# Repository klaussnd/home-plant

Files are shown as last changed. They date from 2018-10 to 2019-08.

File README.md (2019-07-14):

# An automatic watering system for home plants

An open source automatic plant watering system for pot plants in your home.
The system has been employed successfully in my home for several years.
It has a modular design and consists of a measurement module, an irrigation module, and a control module.
A full description as well as some theoretical background can be found [in this paper](http://kschn.users.sf.net/home-plant.pdf).

This repository will contain hardware, firmware, and software utilities.
I am currently in the process of extracting all relevant code from my private repositories.
For now, the repository already contains the hardware.
Code will follow soon.

All circuits and source code are licensed under the terms of the [GNU Affero General Public License](https://www.gnu.org/licenses/agpl-3.0.en.html).

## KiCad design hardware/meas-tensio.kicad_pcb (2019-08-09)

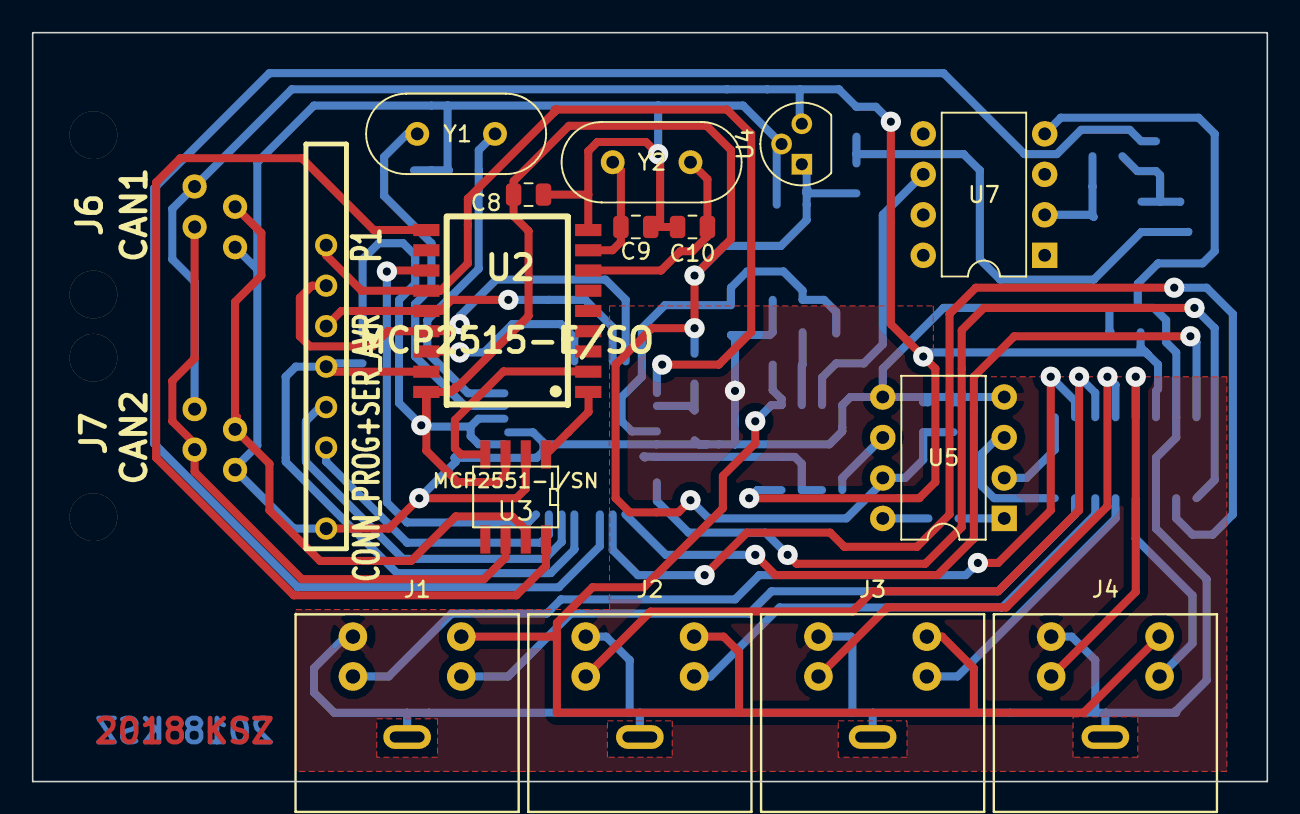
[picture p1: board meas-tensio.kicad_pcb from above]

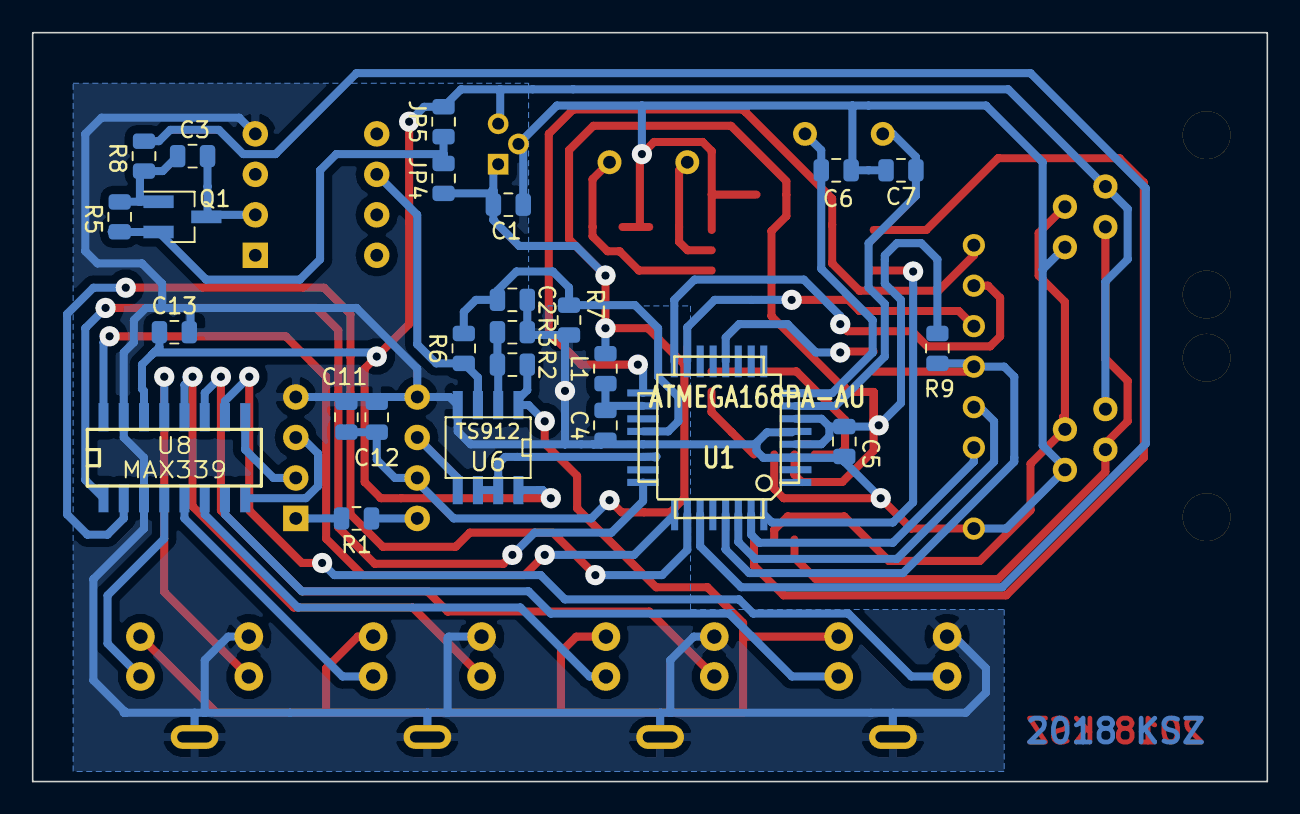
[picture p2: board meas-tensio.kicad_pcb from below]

Board: 2 copper layers, 77.5 x 47.0 mm, 42 parts (25 on the bottom side), 46 nets.

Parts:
C1: 4.7u; C_0805_2012Metric
C2, C3, C4, C5, C8, C11: 100n; C_0805_2012Metric
C6, C7: 22p; C_0805_2012Metric
C9, C10: 33p; C_0805_2012Metric
C12: 10u; C_0805_2012Metric
C13: 10n; C_0805_2012Metric
J1: Tens4; CONN_MINI_DIN_4
J2: Tens3; CONN_MINI_DIN_4
J3: Tens2; CONN_MINI_DIN_4
J4: Tens1; CONN_MINI_DIN_4
J6: CAN1; RJ11_RO
J7: CAN2; RJ11_RO
JP4: ad; R_0805_2012Metric
JP5: a10; R_0805_2012Metric
L1: 10µ; L_0805_2012Metric
P1: CONN_PROG+SER_AVR; SIL-10_MYAVR+SER
Q1: BSS83P; SOT-23_Handsoldering
R1: 1k; R_0805_2012Metric
R2, R3, R5, R6, R7: 100k; R_0805_2012Metric
R8: 10; R_0805_2012Metric
R9: 10k; R_0805_2012Metric
U1: ATMEGA168PA-AU; TQFP32
U2: MCP2515-E/SO; SOIC18_300
U3: MCP2551-I/SN; SOIC8_150
U4: LP2950-5.0_TO92; TO-92
U5: AD623; DIP-8_W7.62mm
U6: TS912; SOIC8_150
U7: REF02; DIP-8_W7.62mm
U8: MAX339; SOIC16_150
Y1: 7.3728MHz; Crystal_HC49-U_Vertical
Y2: 16MHz; Crystal_HC49-U_Vertical

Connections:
/12V: C13.1, J6.2, J7.2, JP5.2, U4.3, U6.8, U8.14
GNDA: C1.2, C2.2, C4.2, C5.2, C6.2, C7.2, C8.2, C9.2, C10.2, C11.2, C12.2, C13.2, J1.4, J1.5, J2.4, J2.5, J3.4, J3.5, J4.4, J4.5, J6.5, J7.5, P1.10, R3.2, R7.2, U1.3, U1.5, U1.21, U2.9, U3.2, U4.2, U5.4, U5.5, U6.4, U7.4, U8.3, U8.15
unnamed: C2.1, R6.2, R7.1, U1.20
unnamed: C3.1, Q1.3, U7.2
unnamed: C3.2, Q1.1, R5.1, R8.2
unnamed: C4.1, L1.2, U1.18
unnamed: C6.1, U1.8, Y1.2
unnamed: C7.1, U1.7, Y1.1
unnamed: C9.1, U2.8, Y2.2
unnamed: C10.1, U2.7, Y2.1
unnamed: J1.1, U8.7
unnamed: J1.2, U8.10
unnamed: J1.3, J2.3, J3.3, J4.3, R2.1, U6.1
unnamed: J2.1, U8.6
unnamed: J2.2, U8.11
unnamed: J3.1, U8.5
unnamed: J3.2, U8.12
unnamed: J4.1, U8.4
unnamed: J4.2, U8.13
unnamed: J6.3, J7.3, U3.7
unnamed: J6.4, J7.4, U3.6
unnamed: JP4.2, JP5.1, Q1.2, R5.2
unnamed: P1.3, U1.17, U2.13
unnamed: P1.4, U1.16, U2.15
unnamed: P1.5, U1.15, U2.14
unnamed: P1.6, R9.2, U1.29, U2.17
unnamed: P1.7, U1.30
unnamed: P1.8, U1.31
unnamed: R1.1, U5.8
unnamed: R1.2, U5.1
unnamed: R2.2, R3.1, U6.2
unnamed: R6.1, U6.3, U7.6
unnamed: R8.1, U1.27
unnamed: U1.12, U2.16
unnamed: U1.22, U6.6, U6.7
unnamed: U1.24, U8.1
unnamed: U1.25, U8.16
unnamed: U1.26, U8.2
unnamed: U1.32, U2.12
unnamed: U2.1, U3.1
unnamed: U2.2, U3.4
unnamed: U2.10, U3.8
unnamed: U5.2, U8.9
unnamed: U5.3, U8.8
unnamed: U5.6, U6.5
VCC: C1.1, C5.1, C8.1, C11.1, C12.1, JP4.1, L1.1, R9.1, U1.4, U1.6, U2.18, U3.3, U4.1, U5.7

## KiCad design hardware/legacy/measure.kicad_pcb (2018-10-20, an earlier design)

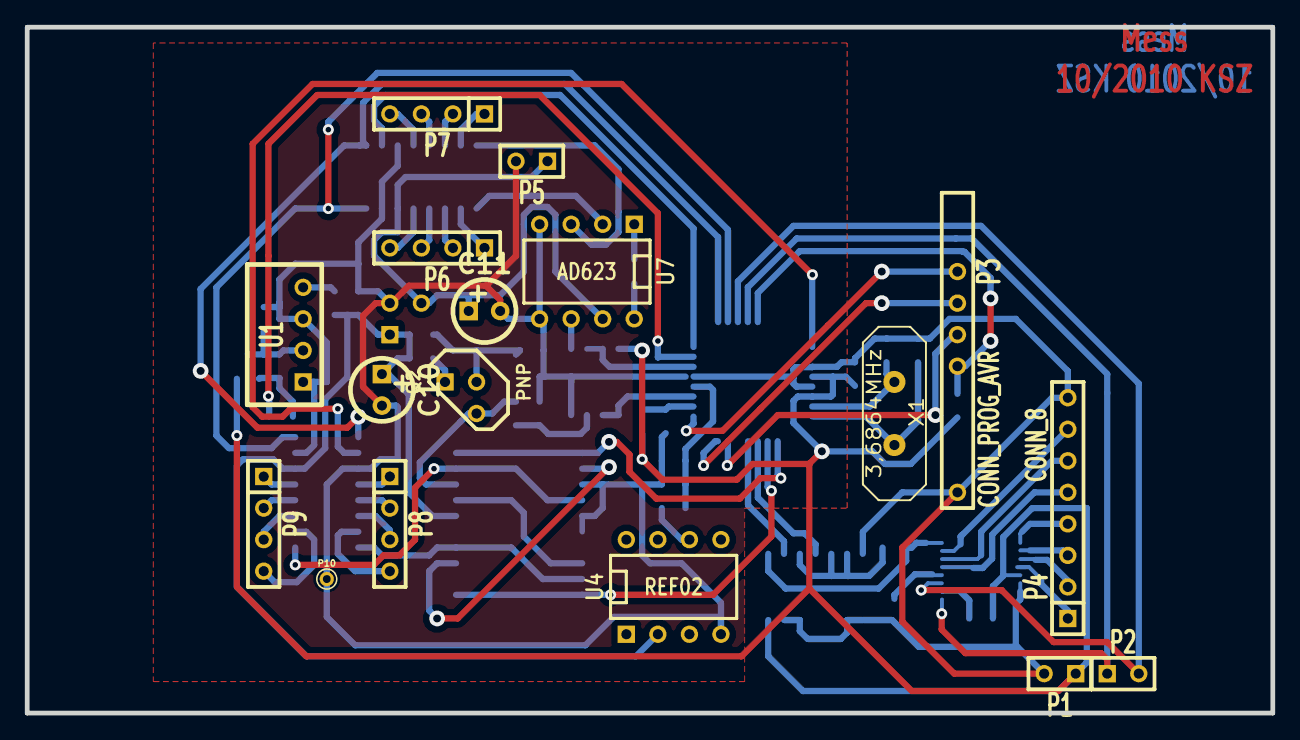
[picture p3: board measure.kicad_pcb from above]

Board: 2 copper layers, 100.3 x 55.2 mm, 49 parts (0 on the bottom side), 69 nets.

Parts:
C1, C2: 0,1µF; SM0805
C3, C4, C5, C7: 100nF; SM0805
C6, C8: 22pF; SM0805
C9: 220pF; SM0805
C10: 0,33µF; Elko_vert_DM5_RM2-5
C11: 0,1µF; Elko_vert_DM5_RM2-5
IC1: ATMEGA8-AI; TQFP32
L1, L2: 10µH; SM0805
P1: VCC; SIL-2
P2: I2C; SIL-2
P3: CONN_PROG_AVR; SIL-10_MYAVR
P4: CONN_8; SIL-8
P5: CONN_2; SIL-2
P6, P7, P8, P9: CONN_4; SIL-4
P10: CONN_1; PINTST
Q1: MOSFET_P; SOT23GDS
Q2: PNP; TO92-INVERT
R1, R7: 1k; SM0805
R2, R8: 1M; SM0805
R3, R4: 10k; SM0805
R9: 100k; SM0805
R10: 2,8k; SM0805
R11: 4,7k; SM0805
R12: 47k; SM0805
R13, R14: 20k; SM0805
U1: SIM1; SIL-4_SIM
U2: 4011; SOIC14_150
U3: ADG728; TSSOP16
U4: REF02; DIP-8__300
U5: TS912; SOIC8_150
U6: 78L10; TO92
U7: AD623; DIP-8__300
U9: MAX333A; SOIC20_300
U10, U11: MAX339; SOIC16_150
X1: 3,6864MHz; HC-18UV

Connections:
+5V: C3.1, IC1.4, IC1.6, L1.1, P1.1, Q1.S, R3.1, R4.1, U2.14, U3.13, U5.8
+24V: C7.2, C10.1, L2.2, R10.1, R11.1, U4.2, U6.1, U9.16, U10.14
/t1: R2.1, U2.1, U3.8
/t4: IC1.28, P2.1, U3.1
/t5: IC1.27, P2.2, U3.3
/t6: R4.2, U3.2
/t8: C9.2, U3.4
/t9: P4.5, U3.5
/t10: P4.6, U3.6
/t11: P4.7, U3.7
/t12: P4.1, U3.12
/t13: P4.2, U3.11
/t14: P4.3, U3.10
/t15: P4.4, U3.9
AGND: C2.1, C3.2, C4.2, C5.2, C6.2, C7.1, C8.2, C9.1, C10.2, C11.2, IC1.3, IC1.5, IC1.21, P1.2, P3.10, P4.8, P5.2, P10.1, R9.2, R12.2, R14.2, U1.1, U1.3, U2.7, U2.8, U2.9, U2.12, U2.13, U3.14, U3.15, U3.16, U4.4, U5.4, U6.2, U7.4, U7.5, U9.3, U9.5, U9.6, U10.3, U10.15, U11.3, U11.15
unnamed: R13.1, U4.6
unnamed: U9.9, U9.14, U10.8
unnamed: P6.2, U11.11
unnamed: P6.3, U11.12
unnamed: P6.4, U11.13
unnamed: IC1.25, U10.1, U11.1
unnamed: P7.4, U11.4
unnamed: P7.3, U11.5
unnamed: P7.2, U11.6
unnamed: P9.2, U10.12
unnamed: P9.3, U10.11
unnamed: P9.4, U10.10
unnamed: P8.1, U10.4
unnamed: P8.2, U10.5
unnamed: P8.3, U10.6
unnamed: P8.4, U10.7
unnamed: P7.1, U11.7
unnamed: P6.1, U11.10
unnamed: U5.5, U7.6
unnamed: C1.2, Q1.G, R1.2
unnamed: C1.1, C2.2, Q1.D, U1.2
unnamed: IC1.15, P3.5
unnamed: C8.1, IC1.8, X1.2
unnamed: C6.1, IC1.7, X1.1
unnamed: U7.2, U11.9
unnamed: U7.3, U11.8
unnamed: R7.2, U7.8
unnamed: R2.2, U2.3, U2.5, U2.6
unnamed: IC1.12, U2.4
unnamed: IC1.23, R1.1
unnamed: IC1.24, U11.2
unnamed: IC1.16, P3.4
unnamed: IC1.26, U10.16, U11.16
unnamed: IC1.17, P3.3
unnamed: IC1.19, U5.1, U5.2
unnamed: IC1.29, P3.6, R3.2
unnamed: C4.1, IC1.18, L1.2
unnamed: IC1.1, U10.2
unnamed: P9.1, U10.13
unnamed: U9.2, U9.13
unnamed: Q2.1, R10.2
unnamed: Q2.2, R11.2, R12.1
unnamed: R8.2, R9.1, U5.3
unnamed: Q2.3, R8.1, U9.18
unnamed: R7.1, U7.1
unnamed: IC1.10, U9.1, U9.20
unnamed: U9.8, U9.17
unnamed: L2.1, U1.4
unnamed: U9.4, U9.19, U10.9
unnamed: C5.1, IC1.20, R13.2, R14.1
unnamed: IC1.22, U5.6, U5.7
unnamed: IC1.11, U9.10, U9.11
unnamed: IC1.13, U2.2
unnamed: C11.1, P5.1, U6.3, U7.7, U11.14

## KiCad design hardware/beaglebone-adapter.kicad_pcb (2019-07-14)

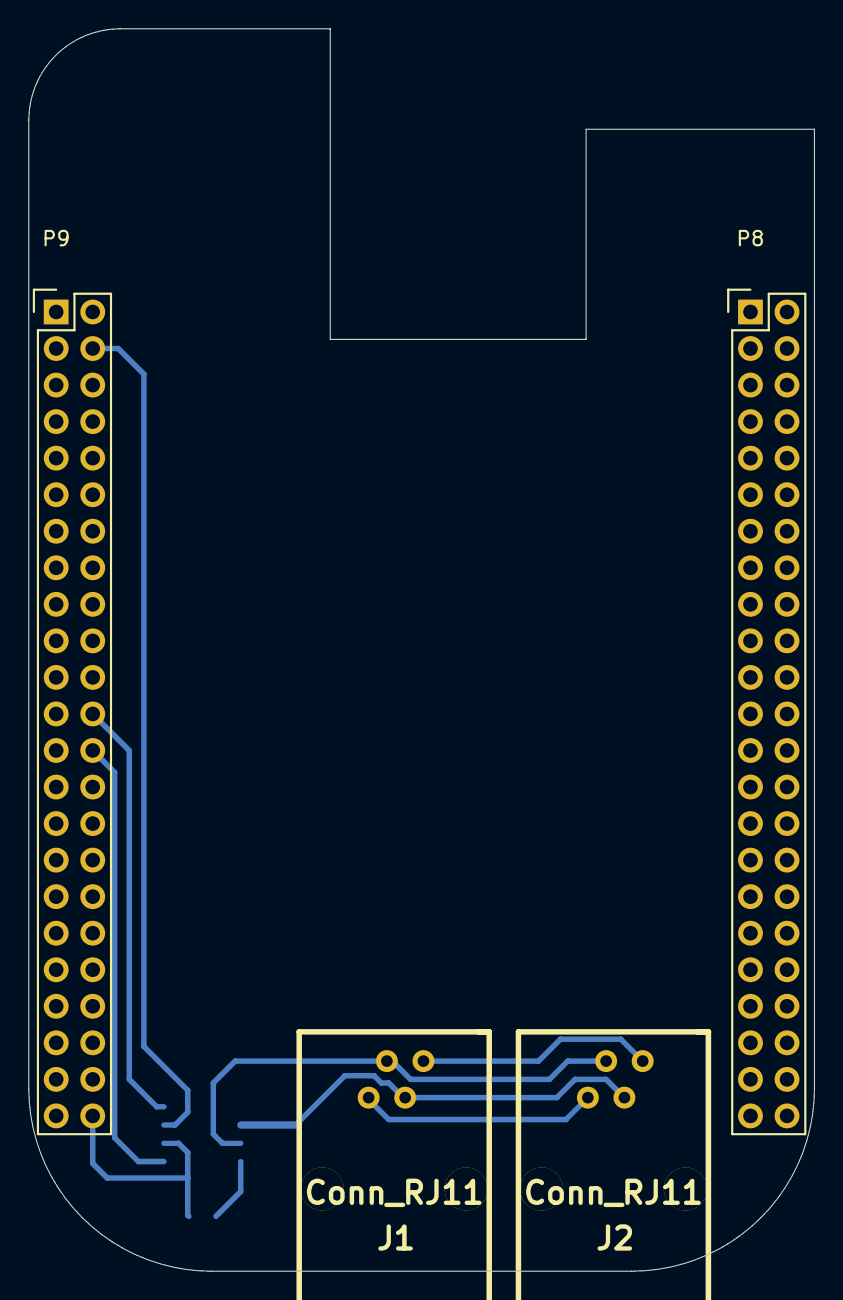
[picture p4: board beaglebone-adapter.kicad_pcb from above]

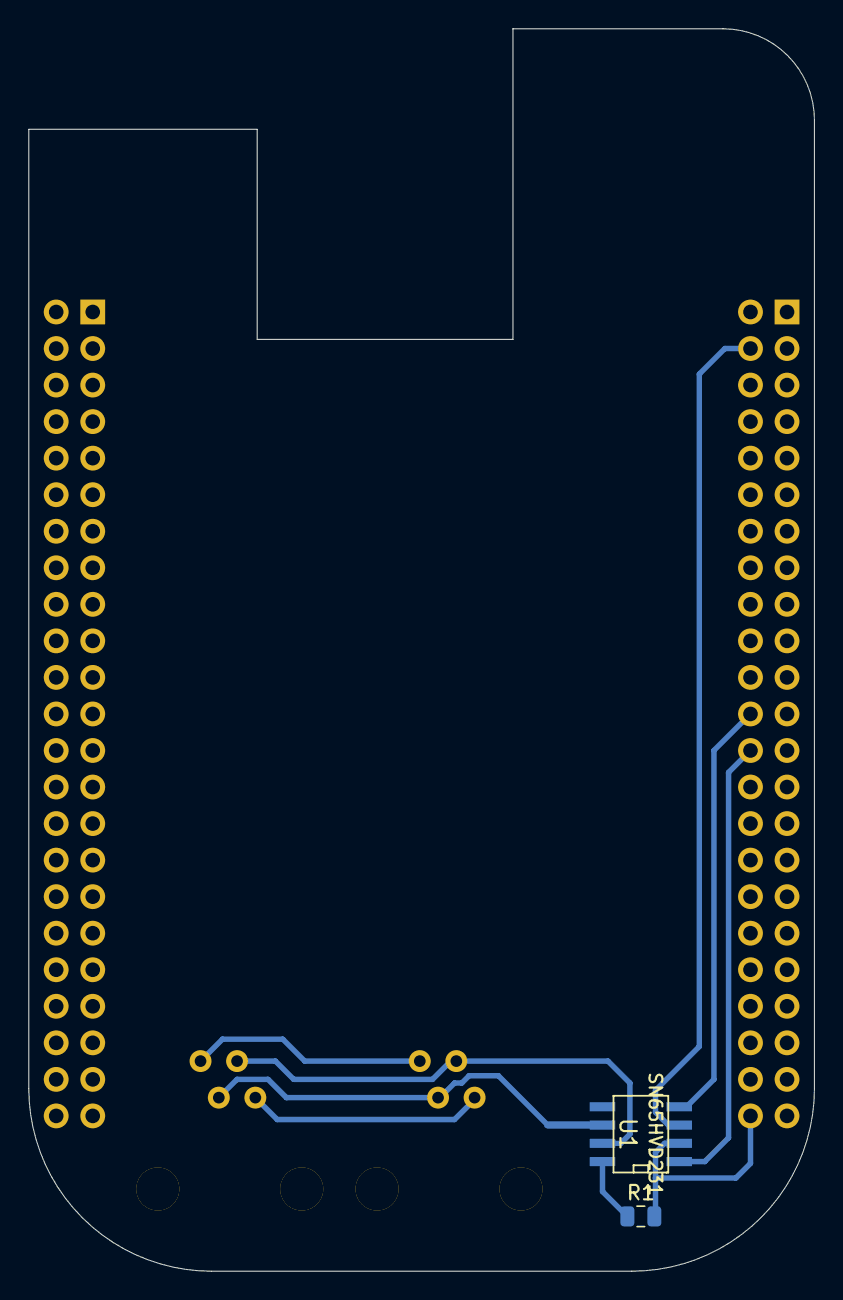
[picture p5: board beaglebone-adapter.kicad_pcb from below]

Board: 2 copper layers, 54.6 x 86.4 mm, 6 parts (2 on the bottom side), 10 nets.

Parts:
J1, J2: Conn_RJ11; RJ11_RO
P8, P9: BeagleBone_Black_Header; Socket_BeagleBone_Black
R1: 10k; R_0805_2012Metric
U1: SN65HVD231; SOIC8_150

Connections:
+3V3: P9.3, P9.4, U1.3
+5V: P9.5, P9.6
GNDD: P8.1, P8.2, P9.1, P9.2, P9.43, P9.44, P9.45, P9.46, R1.2, U1.2
unnamed: J1.2, J2.2
unnamed: J1.3, J2.3, U1.7
unnamed: J1.4, J2.4, U1.6
unnamed: J1.5, J2.5
unnamed: P9.24, U1.4
unnamed: P9.26, U1.1
unnamed: R1.1, U1.8

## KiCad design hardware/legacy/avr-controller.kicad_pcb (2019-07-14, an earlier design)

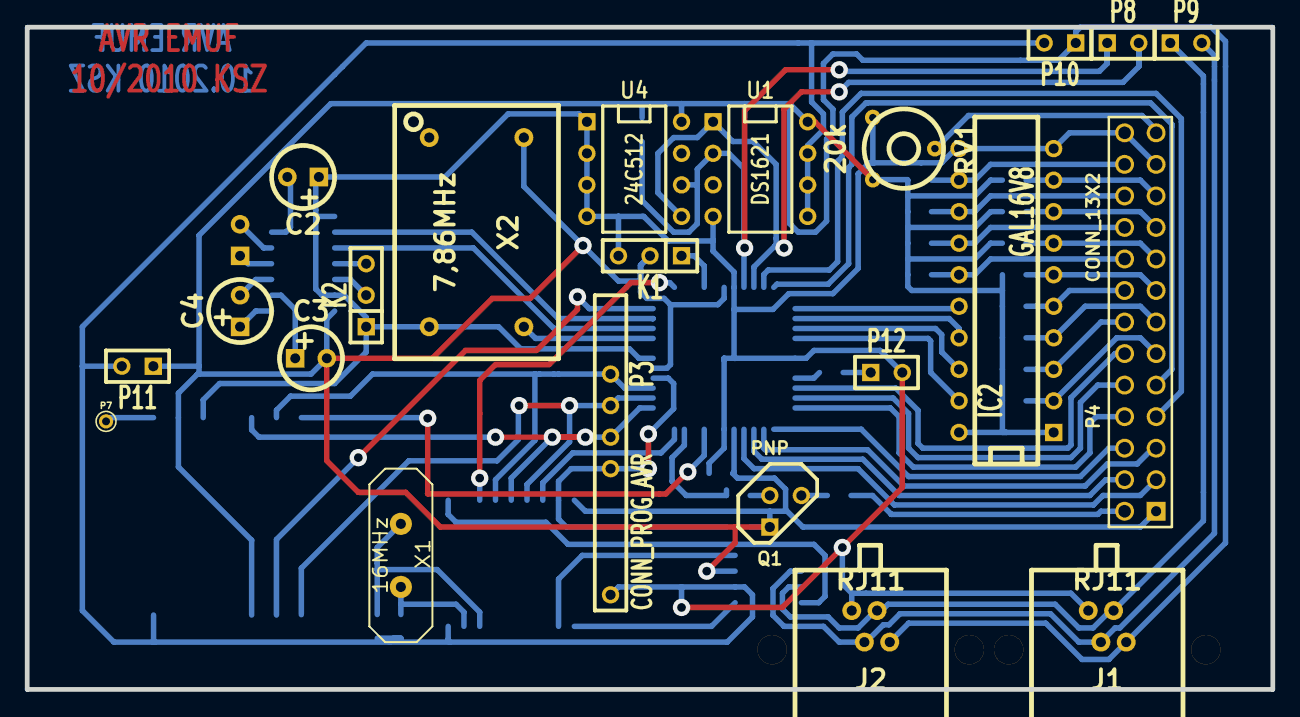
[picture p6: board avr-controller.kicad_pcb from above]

Board: 2 copper layers, 100.3 x 53.3 mm, 49 parts (0 on the bottom side), 64 nets.

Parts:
C1: 100n; SM0805
C2, C3, C4, C5: 1; Elko_vert_DM5_RM2-5
C6, C7: 22pF; SM0805
IC1: ATMEGA32-A; TQFP44
IC2: GAL16V8; DIP-20__300
IC3: MCP2515; SOIC18
IC4: MCP2551; SOIC8_150
J1, J2: RJ11; RJ11_RN
K1, K2: CONN_3; SIL-3
P3: CONN_PROG_AVR; SIL-10_MYAVR
P4: CONN_13X2; pin_array_13x2
P7: ANT; PINTST
P8: i2c; SIL-2
P9: CAN; SIL-2
P10, P11: VCC; SIL-2
P12: LED; SIL-2
Q1: PNP; TO92-INVERT
R1, R2, R3, R4: 10k; SM0805
R5, R6, R7, R9, R10, R11, R12, R13, R14, R15, R16, R17: 100k; SM0805
R8: 33; SM0805
R18: 240; SM0805
RV1: 20k; POT-PT6
U1: DS1621; DIP-8__300
U2: MAX232; SOIC16_150
U3: RFM12
U4: 24C512; DIP-8__300
X1: 16MHz; HC-18UV
X2: 7,86MHz; OSCIL

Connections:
+5V: C1.1, C3.2, IC1.5, IC1.17, IC1.38, IC2.1, IC2.20, IC3.18, IC4.3, J1.2, J2.2, K1.2, P4.1, P10.1, P11.1, Q1.1, R1.1, R3.1, R4.1, R5.1, R6.1, R7.1, R9.1, R10.1, R11.1, R12.1, R13.1, R14.1, R15.1, R16.1, R17.1, RV1.3, U1.8, U2.16, U3.3, U3.9, U4.8, X2.14
GND: C1.2, C2.1, C6.1, C7.1, IC1.6, IC1.18, IC1.28, IC1.39, IC2.10, IC2.11, IC3.9, IC4.2, J1.5, J2.5, K1.3, K2.1, P3.10, P4.23, P4.26, P10.2, P11.2, P12.2, RV1.1, U1.4, U1.5, U1.6, U1.7, U2.10, U2.15, U3.7, U3.10, U4.1, U4.2, U4.3, U4.4, X2.7
unnamed: IC3.1, IC4.1
unnamed: IC4.7, J1.3, J2.3, P9.1
unnamed: IC3.2, IC4.4
unnamed: IC1.41, U3.14
unnamed: C7.2, IC3.7, X1.1
unnamed: C5.1, U2.4
unnamed: C5.2, U2.5
unnamed: C4.1, U2.1
unnamed: C4.2, U2.3
unnamed: C3.1, U2.2
unnamed: C2.2, U2.6
unnamed: IC1.36, P4.4
unnamed: IC1.22, P4.9
unnamed: C6.2, IC3.8, X1.2
unnamed: IC3.10, IC4.8
unnamed: IC1.12, IC3.12
unnamed: IC1.3, IC3.13, P3.3, U3.13
unnamed: IC1.1, IC3.14, P3.5, U3.12
unnamed: IC1.2, IC3.15, P3.4, U3.1
unnamed: IC1.44, IC3.16
unnamed: IC1.4, IC3.17, P3.6, R1.2
unnamed: K2.2, U2.14
unnamed: P12.1, R18.1
unnamed: IC1.30, R18.2
unnamed: IC4.6, J1.4, J2.4, P9.2
unnamed: Q1.2, R2.2
unnamed: Q1.3, R8.1
unnamed: P7.1, U3.8
unnamed: IC1.20, P8.2, R3.2, U1.1, U4.5
unnamed: IC1.8, X2.8
unnamed: IC1.9, U2.12
unnamed: IC1.11, U3.2
unnamed: IC1.21, P4.7
unnamed: IC2.3, P4.14, R16.2
unnamed: IC2.6, P4.15, R13.2
unnamed: IC2.9, P4.21, R10.2
unnamed: IC1.23, IC2.16
unnamed: IC1.10, U2.11
unnamed: K2.3, U2.13
unnamed: IC1.33, P4.8
unnamed: IC1.43, R2.1
unnamed: IC1.24, IC2.17
unnamed: IC1.25, IC2.18
unnamed: IC1.35, P4.5
unnamed: IC1.26, IC2.19
unnamed: IC1.37, P4.3
unnamed: IC1.15, K1.1
unnamed: P4.2, R8.2
unnamed: IC1.31, P4.12
unnamed: IC2.12, P4.24, R5.2
unnamed: P4.25, RV1.2
unnamed: IC2.15, P4.18, R9.2
unnamed: IC2.13, P4.22, R6.2
unnamed: IC2.2, P4.11, R17.2
unnamed: IC2.5, P4.16, R14.2
unnamed: IC2.8, P4.19, R11.2
unnamed: IC2.4, P4.13, R15.2
unnamed: IC2.7, P4.17, R12.2
unnamed: IC1.34, P4.6
unnamed: IC1.32, P4.10
unnamed: IC1.19, P8.1, R4.2, U1.2, U4.6
unnamed: IC2.14, P4.20, R7.2

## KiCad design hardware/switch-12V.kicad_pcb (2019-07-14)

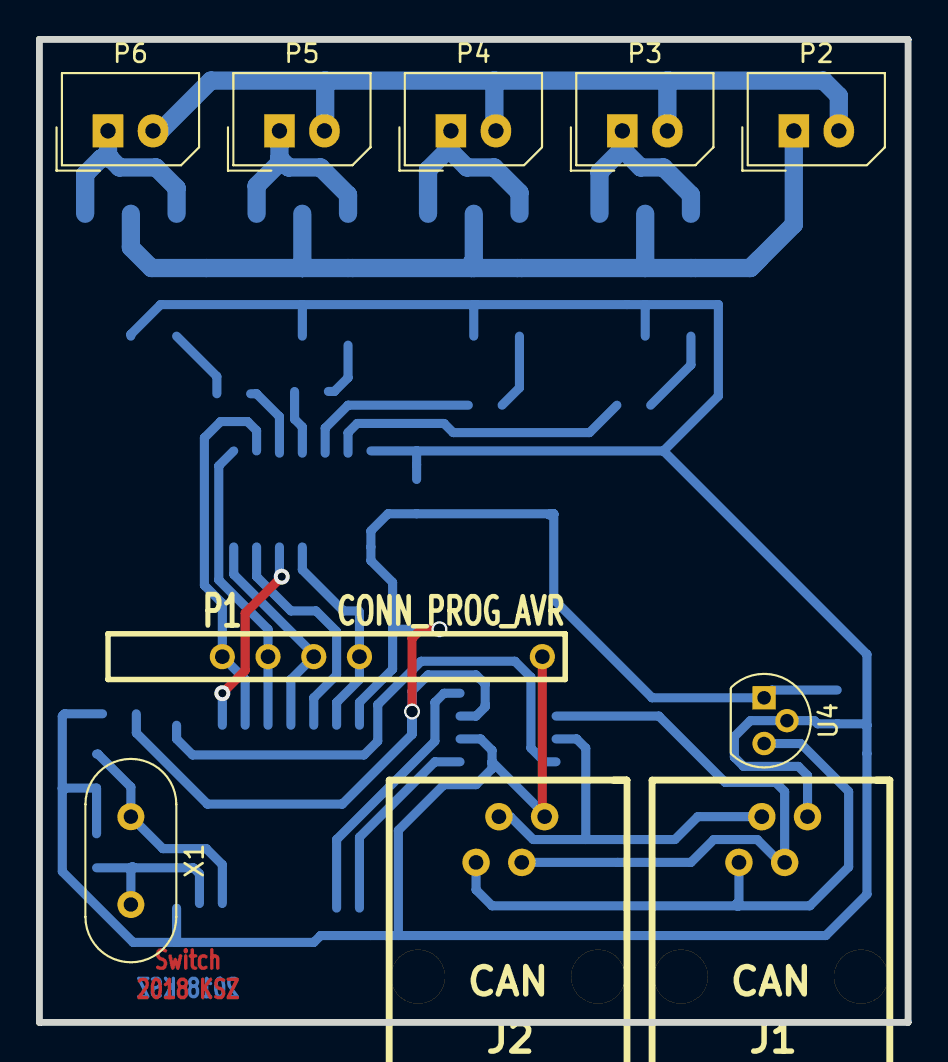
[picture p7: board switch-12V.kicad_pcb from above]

Board: 2 copper layers, 48.3 x 54.6 mm, 27 parts (0 on the bottom side), 30 nets.

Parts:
C1, C4: 100n; C_0805_2012Metric
C2, C3: 33p; C_0805_2012Metric
C5: 4.7u; C_0805_2012Metric
J1, J2: CAN; RJ11_RO
P1: CONN_PROG_AVR; SIL-10_MYAVR
P2: 12V; Molex_SPOX_5267-02A_1x02_P2.50mm_Vertical
P3, P4, P5, P6: Pump; Molex_SPOX_5267-02A_1x02_P2.50mm_Vertical
Q1, Q2, Q3, Q4: photoMOS; SOP6
R1: 10k; R_0805_2012Metric
R2, R3, R4, R5: 330; R_0805_2012Metric
U1: ATTINY24; SOIC14_150
U2: MCP2515; SOIC18_300
U3: MCP2551; SOIC8_150
U4: LP2950-5.0_TO92; TO-92
X1: 16MHz; Crystal_HC49-U_Vertical

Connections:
+5V: C1.1, C4.1, C5.1, R1.1, U1.1, U2.18, U3.3, U4.1
/12V+: P2.2, P3.2, P4.2, P5.2, P6.2
/12V-: P2.1, Q1.5, Q2.5, Q3.5, Q4.5
/X1: P3.1, Q1.4, Q1.6
/X2: P4.1, Q2.4, Q2.6
/X3: P5.1, Q3.4, Q3.6
/X4: P6.1, Q4.4, Q4.6
GND: C1.2, C2.1, C3.1, C4.2, C5.2, J1.5, J2.5, P1.10, Q1.2, Q2.2, Q3.2, Q4.2, U1.14, U2.9, U3.2, U4.2
unnamed: C2.2, U2.7, X1.1
unnamed: C3.2, U2.8, X1.2
unnamed: J1.2, J2.2, U4.3
unnamed: J1.3, J2.3, U3.7
unnamed: J1.4, J2.4, U3.6
unnamed: P1.3, U1.9, U2.13
unnamed: P1.4, U1.8, U2.14
unnamed: P1.5, U1.7, U2.15
unnamed: P1.6, R1.2, U1.4, U2.17
unnamed: Q1.1, R2.1
unnamed: Q2.1, R3.1
unnamed: Q3.1, R4.1
unnamed: Q4.1, R5.1
unnamed: R2.2, U1.13
unnamed: R3.2, U1.12
unnamed: R4.2, U1.11
unnamed: R5.2, U1.10
unnamed: U1.5, U2.12
unnamed: U1.6, U2.16
unnamed: U2.1, U3.1
unnamed: U2.2, U3.4
unnamed: U2.10, U3.8

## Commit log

2018-10-20 Added boards
    [giess-mess.brd, giess-mess.sch, giess-schalt.brd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]
2018-10-20 imrpoved schematics/boards
    [giess-mess.brd, giess-mess.sch]
2018-10-20 board giess-schalt adjusted for Reichelt's new RJ12 connectors
    [giess-schalt.brd]
2018-10-20 board giess-schalt improved
    [giess-schalt.brd]
2018-10-20 projekt: avr-emuf & giess-mess boards layout improved
    [giess-mess.brd]
2018-10-20 Convert measurement schematics to new kicad version
    [giess-mess.sch]
2018-10-20 Update switching module schematic to new KiCad version
    [giess-schalt.sch]
2018-10-20 Fix ground of instrument amplifier
    [giess-mess.sch]
2018-10-20 Make schematics up to date
    [giess-schalt.sch]
2018-10-20 Add tensiometer measurement module
    [meas-tensio.sch]
2018-10-20 Improve tensiometer module.
    Also allow changing tensiometer supply voltage variant with jumpers / non-soldered resistors.
    [meas-tensio.sch]
2018-10-20 Add measurement module for capacitive soil water probe Giesomat
    [meas-capacity.sch]
2018-10-20 Connect Vcc and GND from CAN interface
    [meas-tensio.sch]
2018-10-20 Add simple RJ11 connector symbol and use it
    [meas-capacity.sch, meas-tensio.sch]
2018-10-20 Update tensiometer schematic to newest kicad version 5
    [meas-tensio.sch]
2018-10-20 Update capacitive water content module to new kicad version 5
    [meas-capacity.sch]
2018-10-20 Change select pin
    [meas-capacity.sch, meas-tensio.sch]
2018-10-20 Update annotation
    [meas-capacity.sch, meas-tensio.sch]
2018-10-20 Water content capacity board
    [meas-capacity.kicad_pcb, meas-capacity.sch]
2018-10-20 Convert switching module to new KiCad version 5
    [giess-schalt.sch]
2018-10-20 Rename switching module
    [switch.kicad_pcb, switch.sch]
2018-10-20 Convert switching module PCB to new KiCad format
    [switch.kicad_pcb]
2018-10-20 Move measurement module v1 into legacy folder
    [measure.kicad_pcb, measure.sch]
2018-10-20 Convert board into new KiCad format
    [measure.kicad_pcb]
2018-10-20 Add 5V regulator to capacity measurement module
    [meas-capacity.kicad_pcb, meas-capacity.sch]
2018-10-20 Update switching module
    [switch.kicad_pcb, switch.sch]
2018-10-20 Adjust tensiometer module for 12V supply voltage
    [meas-tensio.sch]
2018-10-20 Change capacitor value in water content and switching modules
    [meas-capacity.sch, switch.sch]
2018-10-20 Use Mini-DIN plug
    [meas-capacity.kicad_pcb, meas-capacity.sch]
2018-10-20 Move all plugs onto one side of the PCB
    [meas-capacity.kicad_pcb]
2018-10-20 Fix tensiometer schematic
    [meas-tensio.sch]
2018-10-20 Vcc of instrumentation amplifier is 5V instead of 12V
    [meas-tensio.sch]
2018-10-20 Add tensiometer board
    [meas-tensio.kicad_pcb]
2018-10-20 Fix edge
    [meas-tensio.kicad_pcb]
2018-10-20 Adjust edge, add text
    [meas-capacity.kicad_pcb]
2018-10-20 Improve analogue part
    [meas-tensio.kicad_pcb, meas-tensio.sch]
2019-07-14 Add CAN adapter for beagle bone
    [beaglebone-adapter.kicad_pcb, beaglebone-adapter.sch]
2019-07-14 Rename switching board
    [switch-230V.kicad_pcb, switch-230V.sch]
2019-07-14 Move AVR controller to legacy folder
    [avr-controller.brd, avr-controller.sch]
2019-07-14 Convert to new KiCad format
    [avr-controller.brd, avr-controller.kicad_pcb]
2019-07-14 Move hardware into sub-folder
    [avr-controller.kicad_pcb, avr-controller.sch, beaglebone-adapter.kicad_pcb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]
2019-07-14 Add submodule for kicad libraries and modules
2019-07-14 Update kicad submodule
2019-07-14 Add 12V version of switching module
    [switch-12V.kicad_pcb, switch-12V.sch]
2019-07-14 Correct capacitor value
    [meas-capacity.sch, meas-tensio.sch, switch-12V.sch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]
2019-07-14 Update footprint from module. Fix pad connection to ground plane.
    [switch-12V.kicad_pcb]
2019-07-14 Connect screen of Mini-DIN plug to GND
    [meas-capacity.kicad_pcb, meas-capacity.sch, meas-tensio.kicad_pcb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]
2019-07-14 Fix relay wiring of 12V switch board
    [switch-12V.kicad_pcb, switch-12V.sch]
2019-07-14 Fix conflicting capacitor placement
    [meas-capacity.kicad_pcb, meas-tensio.kicad_pcb]
2019-07-14 Remove unnecessary jumper. Remove ground loop.
    [meas-tensio.kicad_pcb, meas-tensio.sch]
2019-07-21 Improve silk
    [meas-capacity.kicad_pcb, meas-tensio.kicad_pcb]
2019-08-09 Improve label position
    [meas-tensio.kicad_pcb]
